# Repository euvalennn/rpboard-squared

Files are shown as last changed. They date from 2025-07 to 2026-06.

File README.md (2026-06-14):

# RPBoard²

RPBoard² is a simple RP2350-based board with multiple convenient features built-in. It's my first "actual" PCB project (I only did a hackpad before)

## Motivation

I wanted to build a devboard to learn more about actual PCB design and electronics, instead of using pre-made boards. I considered it as a personal challenge and ended up learning a lot on the two weeks it took me to make it :D

## Features:

- RP2350A MCU
- JST Debug header
- Built-in lithium battery support
- microSD card reader
- On-board RGB LED on GPIO25 (neopixel)
- QWIIC / Stemma QT I2C connector
- USB-C connector
- 16MB flash memory

## Built project:

| Front | Back |
| --- | --- |
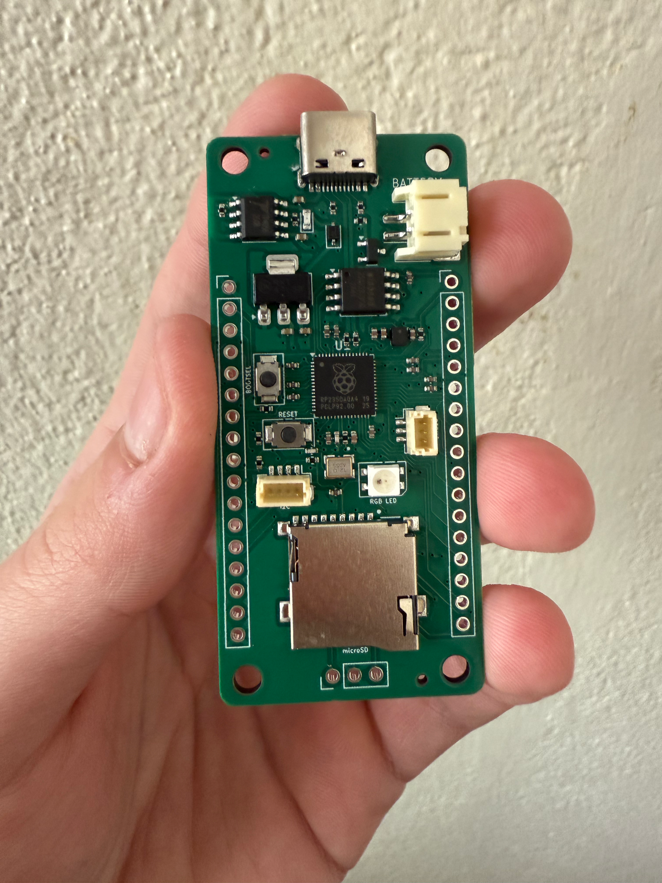
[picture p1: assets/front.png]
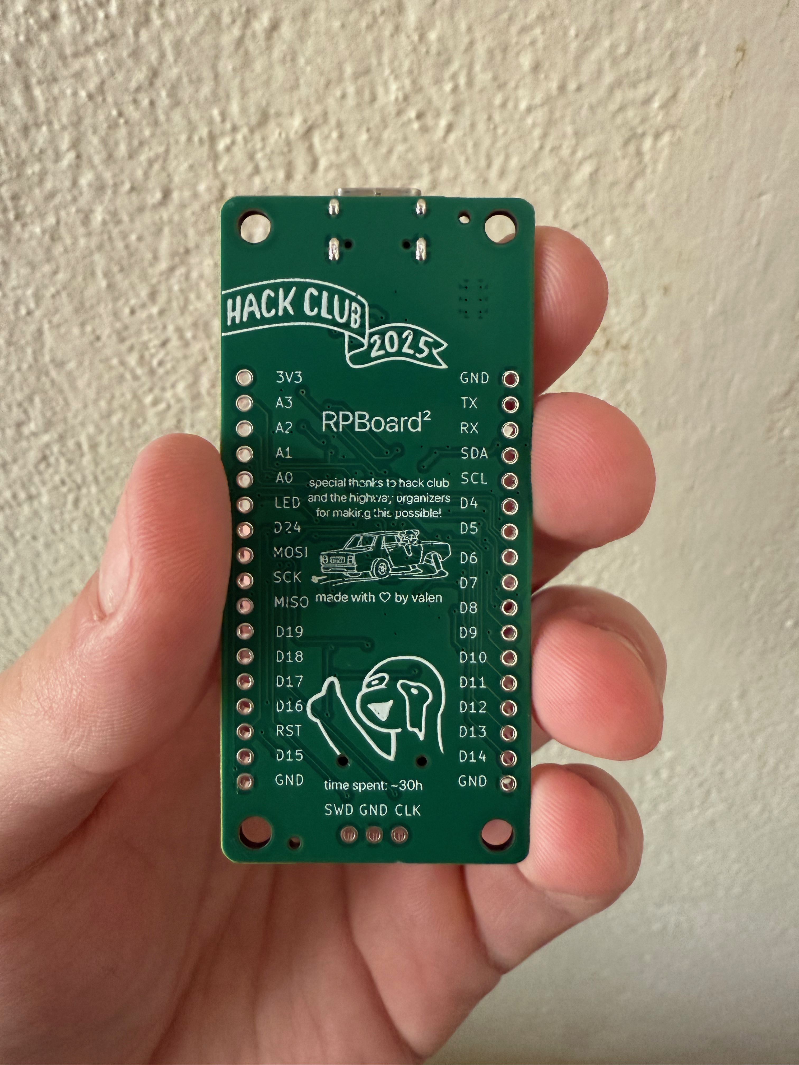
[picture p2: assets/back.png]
|  |  |

## PCB and schematic:

### Schematic:

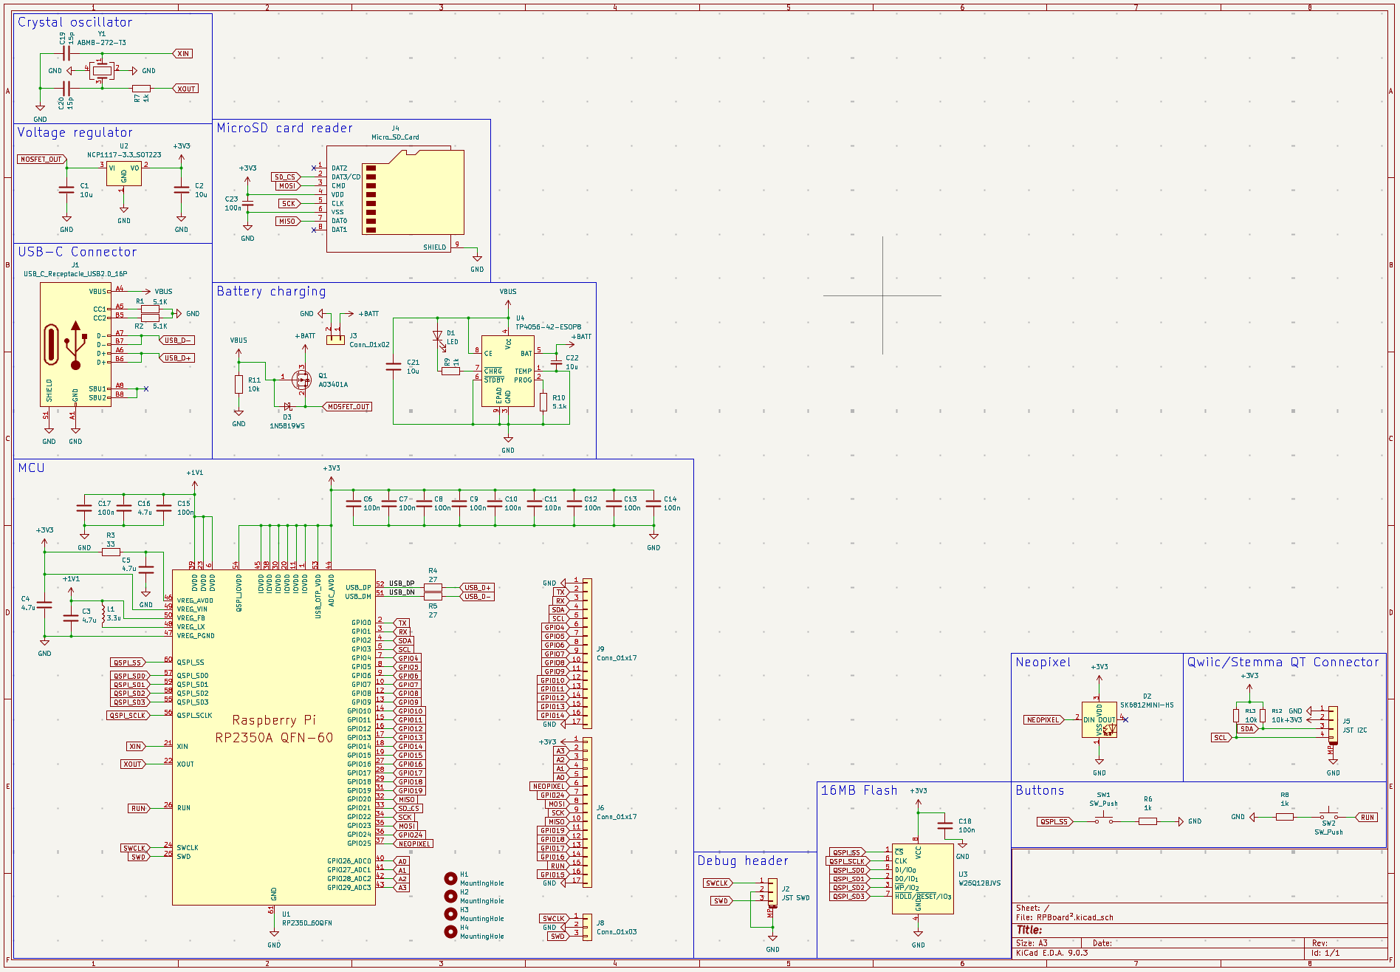
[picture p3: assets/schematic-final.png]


### PCB:

| PCB editor | 3D viewer |
| --- | --- |
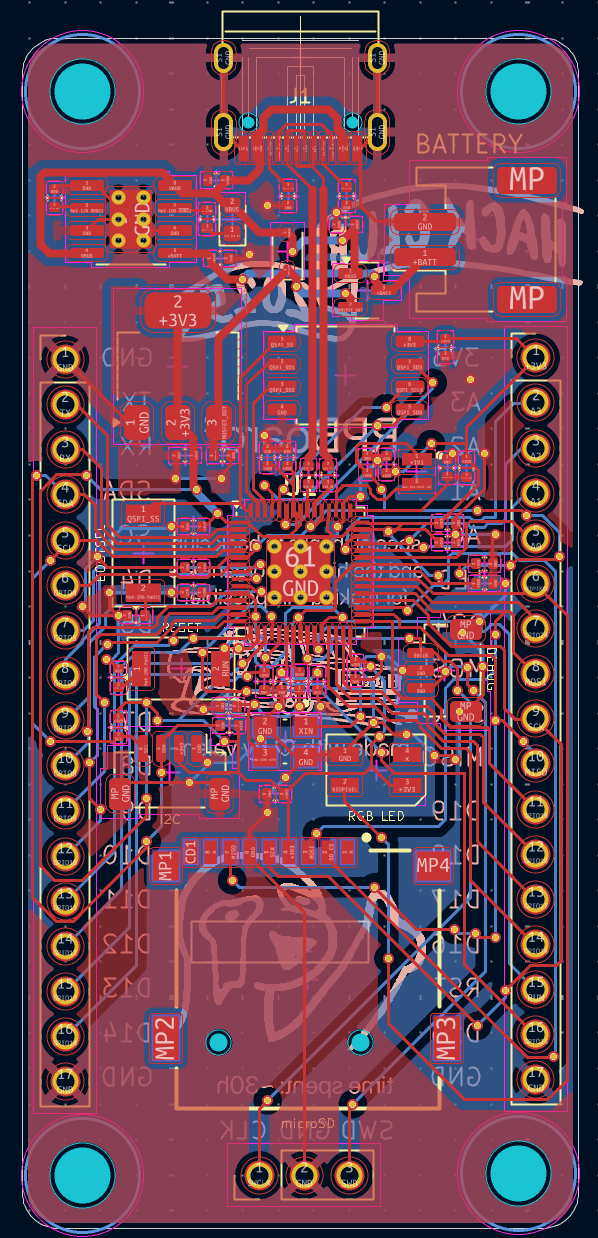
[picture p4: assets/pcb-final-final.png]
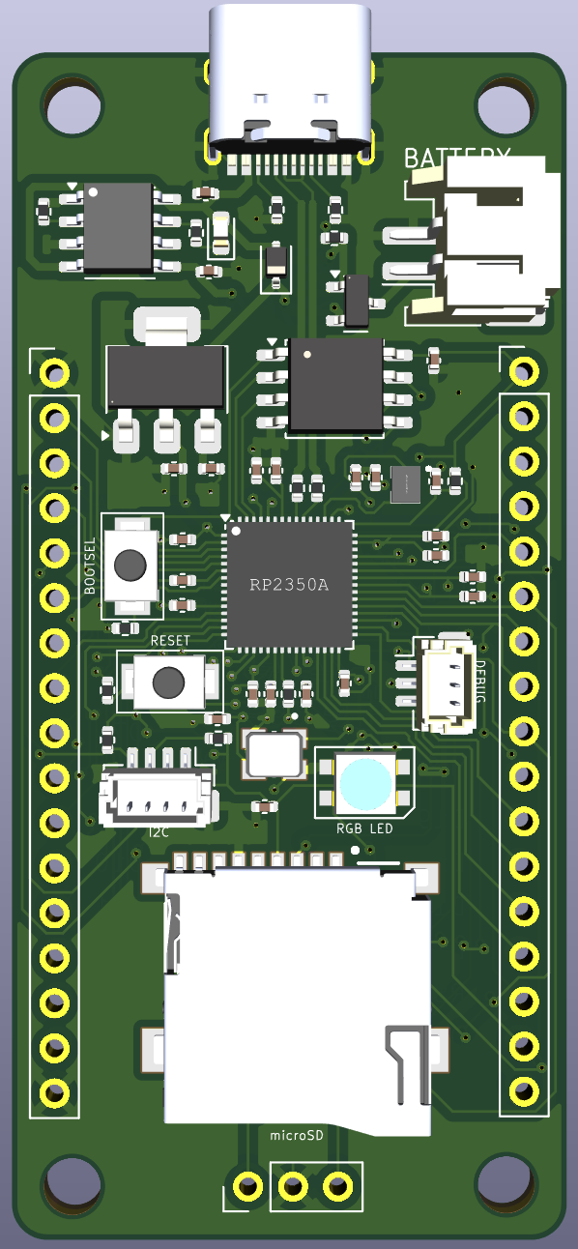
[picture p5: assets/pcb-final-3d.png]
|  |  |

Both the PCB and the schematic were designed using KiCad. The PCB is a 2-layer board with a ground pour on both layers.

## BOM:

| Name | Description | Quantity | LCSC Part # | Total price |
| --- | --- | --- | --- | --- |
| CL05A106MP5NUNC | 10V 10uF X5R ±20% 0402 Multilayer Ceramic Capacitors MLCC - SMD/SMT ROHS | 4 | C315248 | $0.1640 |
| CGA0402X7R104K160GT | 16V 100nF X7R ±10% 0402 Multilayer Ceramic Capacitors MLCC - SMD/SMT ROHS | 13 | C6119799 | $0.0342 |
| CL05A475MP5NRNC | 10V 4.7uF X5R ±20% 0402 Multilayer Ceramic Capacitors MLCC - SMD/SMT ROHS | 4 | C23733 | $0.0384 |
| CC0402JRNPO9BN150 | 50V 15pF NP0 ±5% 0402 Multilayer Ceramic Capacitors MLCC - SMD/SMT ROHS | 2 | C106997 | $0.0220 |
| XL-1608SURC-06 | 20mA 225mcd Water Clear op View Mount 620nm~630nm Red 120° 50mW 2.3V 0603 LED Indication - Discrete ROHS | 1 | C965799 | $0.0620 |
| SK6812MINI-HS | SMD,3.5x3.7mm RGB LEDs(Built-in IC) ROHS | 1 | C2922787 | $0.4665 |
| 1N5819WS | 40V 600mV@1A 1A SOD-323 Schottky Diodes ROHS | 1 | C191023 | $0.0192 |
| TYPE-C-31-M-12 | 5A 1 16P Female Type-C SMD USB Connectors ROHS | 1 | C165948 | $0.3394 |
| BM03B-SRSS-TB(LF)(SN) | 1x3P 3P SH Tin 3 -25℃~+85℃ 1A 1 1mm Copper Alloy Surface Mount,Vertical SMD,P=1mm Wire To Board Connector ROHS | 1 | C160389 | $1.1070 |
| S2B-PH-SM4-TB(LF)(SN) | 1x2P 2P PH Tin 2 -25℃~+85℃ 2A 1 2mm Copper Alloy Surface Mount, Right Angle SMD,P=2mm,Surface Mount,Right Angle Wire To Board Connector ROHS | 1 | C295747 | $0.9295 |
| TF-01A | 1.85mm Connector and Ejector MicroSD Card (TF Card) Push-Push SMD SD Card / Memory Card Connector ROHS | 1 | C91145 | $0.3372 |
| BM04B-SRSS-TB(LF)(SN) | 1x4P 4P SH Tin 4 -25℃~+85℃ 1A 1 1mm Copper Alloy Surface Mount,Vertical SMD,P=1mm Wire To Board Connector ROHS | 1 | C160390 | $0.9105 |
| AOTA-B201610S3R3-101-T | 0806 Power Inductors ROHS | 1 | C42411119 | $1.3680 |
| AO3401A | 30V 4.2A 120mΩ@2.5V 1.4W 1.3V@250uA 1 P-Channel SOT-23 MOSFETs ROHS | 1 | C347476 | $0.2990 |
| 0402WGF5101TCE | 62.5mW Thick Film Resistor 50V ±100ppm/℃ ±1% 5.1kΩ 0402 Chip Resistor - Surface Mount ROHS | 3 | C25905 | $0.0030 |
| 0402WGF1002TCE | 62.5mW Thick Film Resistor 50V ±100ppm/℃ ±1% 10kΩ 0402 Chip Resistor - Surface Mount ROHS | 3 | C25744 | $0.0030 |
| 0402WGF330JTCE | 62.5mW Thick Film Resistor 50V ±100ppm/℃ ±1% 33Ω 0402 Chip Resistor - Surface Mount ROHS | 1 | C25105 | $0.0010 |
| RC0402FR-0727RL | 62.5mW Thick Film Resistor 50V ±100ppm/℃ ±1% 27Ω 0402 Chip Resistor - Surface Mount ROHS | 2 | C138021 | $0.0120 |
| FRC0402J102 TS | 62.5mW Thick Film Resistor 50V ±100ppm/℃ ±5% 1kΩ 0402 Chip Resistor - Surface Mount ROHS | 4 | C2906899 | $0.0080 |
| TS-1088-AR02016 | Without Bracket 50mA 4mm 100,000 Cycles 12V 1.6N 3mm 2mm Round Button Surface Mount,Vertical SPST SMD Tactile Switches ROHS | 2 | C720477 | $0.1692 |
| RP2350A | QFN-60-EP(7x7) Microcontrollers (MCU/MPU/SOC) ROHS | 1 | C42411118 | $2.1330 |
| NCP1117ST33T3G | 62dB@(120Hz) 1A Fixed 3.3V Positive 20V SOT-223 Voltage Regulators - Linear, Low Drop Out (LDO) Regulators ROHS | 1 | C26537 | $0.5098 |
| W25Q128JVSIQ | 128Mbit SPI 133MHz SOIC-8-208mil NOR FLASH ROHS | 1 | C97521 | $1.9590 |
| TP4056-42-ESOP8 | 4V~8V Lithium-ion/Polymer 1 1A ESOP-8 Battery Management ROHS | 1 | C16581 | $0.3438 |
| ABM8-272-T3 | SMD3225-4P Crystals ROHS | 1 | C20625731 | $2.1000 |
| PCB Price | JLCPCB | 5 | N/A | $2.00 |
| Economic PCBA setup fee | JLCPCB | N/A | N/A | $8.00 |
| PCBA stencil | JLCPCB | N/A | N/A | $1.50 |
| Extended components fee | JLCPCB | N/A | N/A | $51.00 |
| SMT assembly | JLCPCB | N/A | N/A | $1.13 |
| Special components fee | JLCPCB | N/A | N/A | $0.06 |
| Nitrogen reflow soldering | JLCPCB | N/A | N/A | $0.82 |
| Shipping to Argentina (cheapest) | DHL Express (FedEx appears to be cheaper on cart page but adds an additional remote area surcharge at checkout, DHL ends up being the cheapest option) | N/A | N/A | $33.33 |
| Subtotal | N/A | N/A | N/A | $111.18 |
| Total after $80 JLCPCB coupon | N/A | N/A | N/A | $31.18 |

Although DHL shipping is expensive, it's the cheapest option for Argentina. FedEx has a cheaper price in the cart page, but after checking out it adds a $50+ remote area surcharge.

## Special thanks:

Thanks to Hack Club and the highway organizing team for all their efforts to make this possible. I would have never thought I'd be capable of something like this, yet highway gave me the motivation I needed to actually learn and design, and the funding to make it real.

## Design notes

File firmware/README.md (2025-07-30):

# Firmware

This basic CircuitPython code makes the integrated neopixel blink. It's a basic demo of the board's functionalities.

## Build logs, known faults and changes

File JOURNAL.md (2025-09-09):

---
title: "RPBoard²"
author: "@valen"
description: "Simple RP2350-based devboard"
created_at: "2025-07-15"
---

### Total time spent: 39h

# July 15: Started reading hardware design guide + basic schematic design

I wanted to get started doing the schematic as I was reading the guide instead of just reading, so that's what I did :D

Here's how my schematic is looking for now: (ik it's really basic but I'm just getting started and following the guide, I'll add a ton of features once I have the basics done. also I spent most of the time trying to understand what I'm doing instead of just copy pasting that's why it took me so long lol)

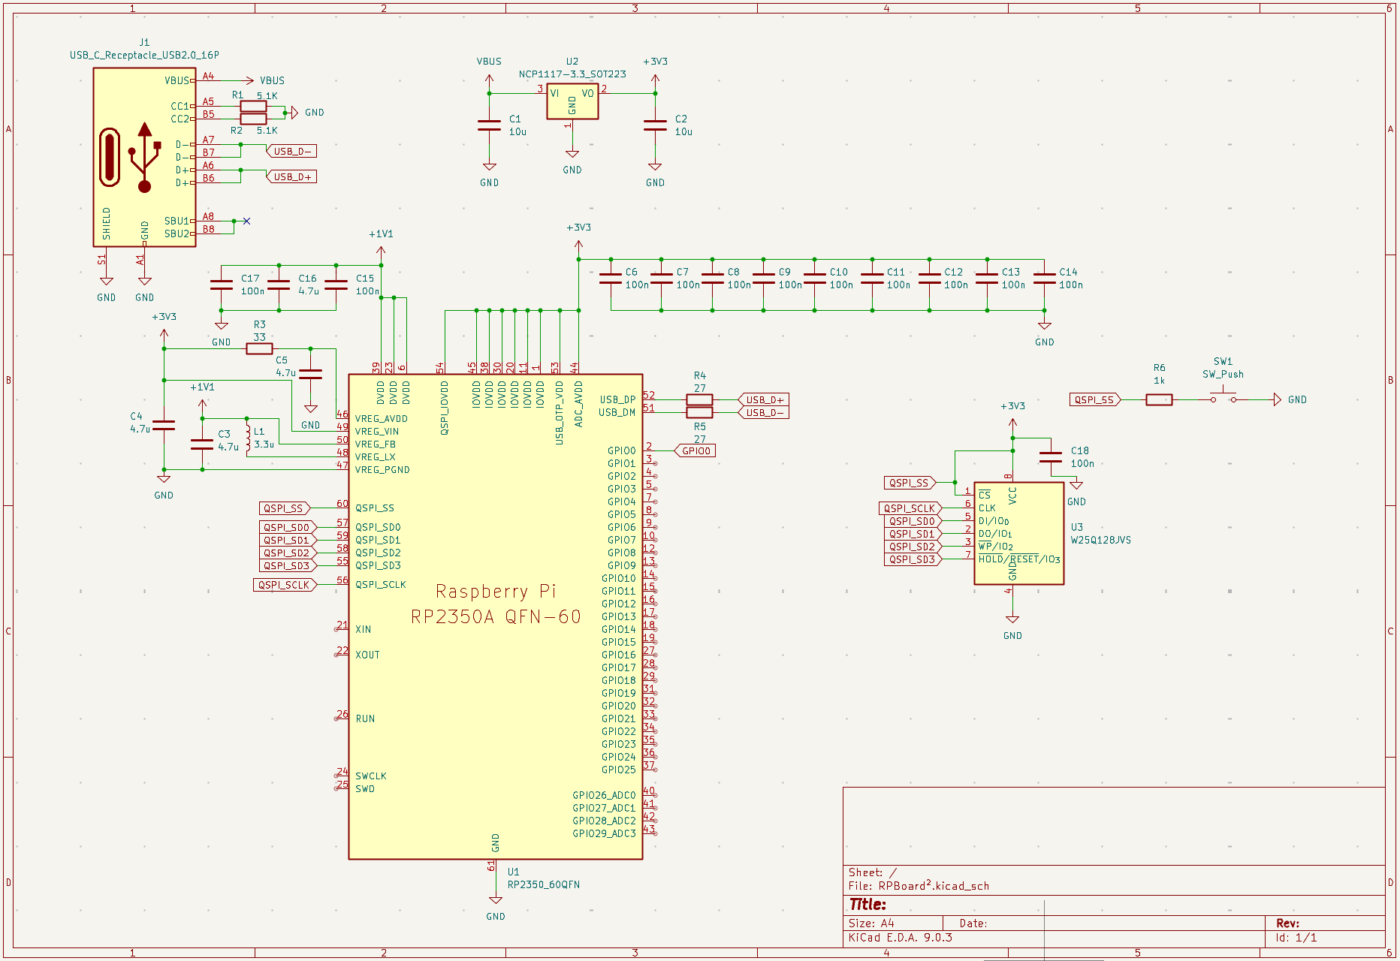
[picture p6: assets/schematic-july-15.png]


Only thing I changed for now is the USB connector for it to be USB-C, it's not really too different from the micro USB symbol but that's probably because I'm using a 16 pin connector.

As for the flash, it took me quite some time to figure out how to wire it because the guide wasn't really clear but it ended up being easier than I thought, idk why I got so confused lol

Then I also added decoupling caps on the power pins (took me some time to understand what they were and why I should add them but after quite a lot of googling I think I figured it out).

And the last thing I added to my schematic was the external components needed to make the on-chip voltage regulator work properly, I copied that from the guide since I didn't want to mess up and for some reason the guide really insists on using a specific inductor so might as well do that lmao

To finish with the basics of the schematic I'm only missing the crystal oscillator, a debug connector (optional but I'll add it anyways for convenience) and a reset button (optional too but obviously nice to have).

As for additional features, for now I'm planning on adding lipo battery support, a Qwiic connector, a microSD card slot and maybe even a small OLED depending on how much space I have left

Well hopefully tomorrow I'll finish with the basics and start adding some actually interesting features!! :D

**Time spent this session: 4h**

# July 16: Finished basic features + lot of research into charging circuit

Today I finished the basic features needed to make the board work! It's really simple though so I don't think its worth it to even include a screenshot of that.

What I did spend a lot of time on though is trying to figure out how I'd implement battery charging into the board, and after a few hours of googling and reading datasheets I think I'm gonna use a TP4056 with its "typical application" circuit as the charging IC (screenshot below) and then use a MOSFET so load switches to VBUS when USB is plugged in. From what I've seen I also have to include a diode in the load sharing circuit for protection. I'll try to add the charging aspect tomorrow and then see if someone can take a look at my schematic and tell me if there's any mistakes, maybe I'm overthinking this too much lol

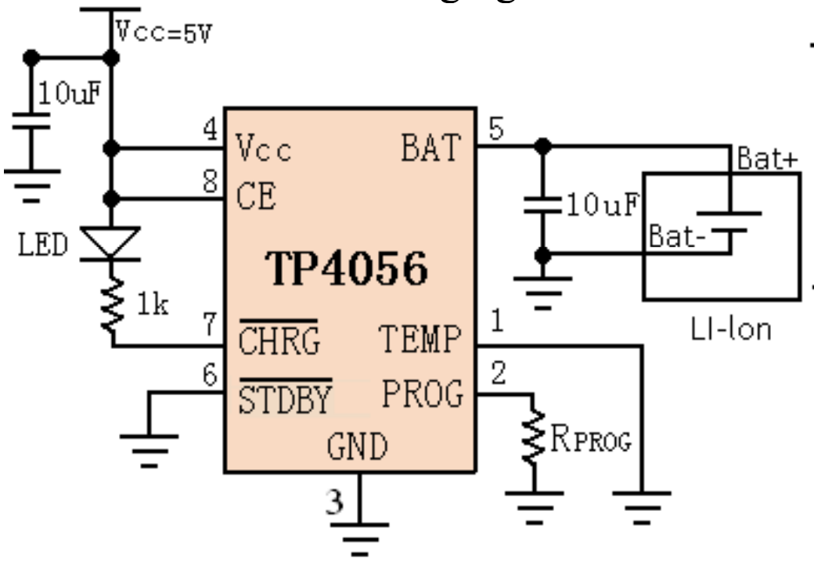
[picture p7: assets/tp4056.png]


microSD card reader shouldn't be too hard to wire, and a Qwiic connector should be even easier. I'm not sure if I'll end up adding the OLED though, since I'm planning on getting PCBA for this board and also aliexpress takes like 2 months to ship to me so I wouldn't be able to build it in time unless I source it locally (in that case I'd pay the price difference between getting it locally and ali out of pocket since the cost of locally sourcing an OLED is lower than the customs fees I'd be charged with aliexpress lmao)

Hopefully this approach works because I spent a lot of time figuring it out 😭

**Time spent this session: 3h**

# July 17: Finished charging circuit + tidied up schematic

I finally finished implementing the charging circuit in my schematic, it took me way longer than it should have but I wanted to make sure I was doing everything right becasue no power = no board :(

This is how my charging circuit looks now:

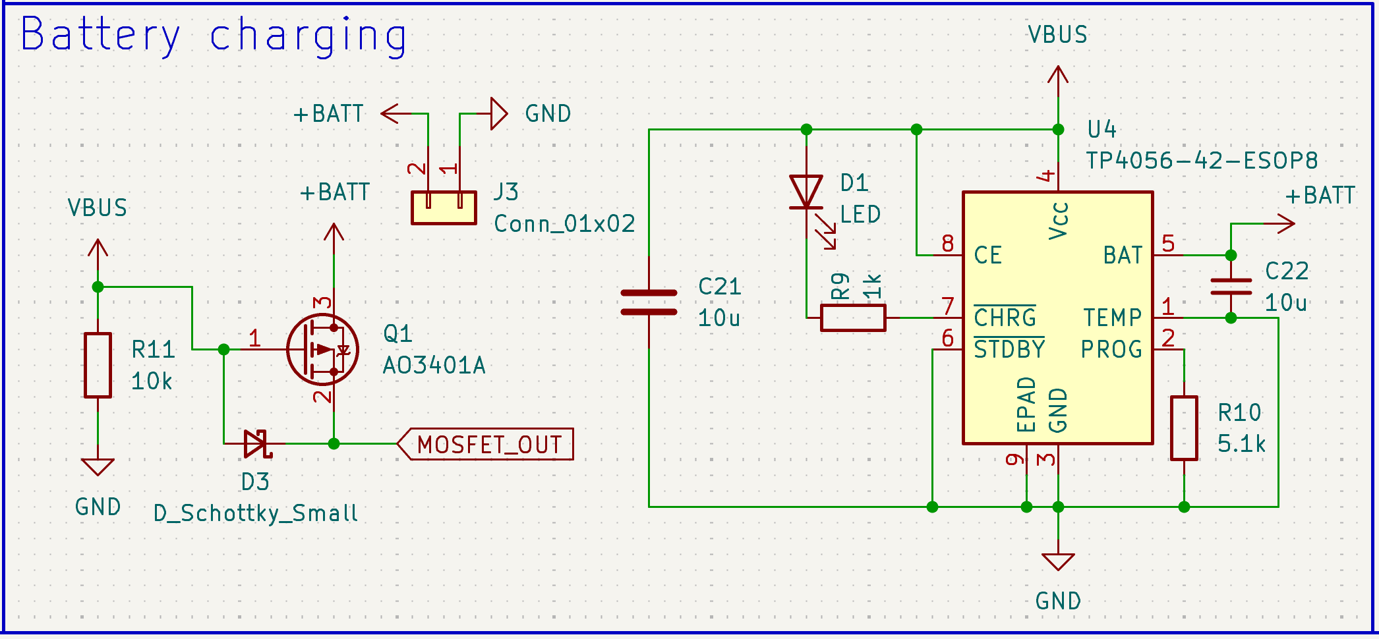
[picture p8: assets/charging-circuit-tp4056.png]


The 5.1k resistor should give me a charging current of around 200-250 mA, which I think is fine for small LiPo batteries. Anyways, if I were to change my mind later I could just swap that resistor.

I also switched the voltage regulator to take in the output from the MOSFET instead of just VBUS:

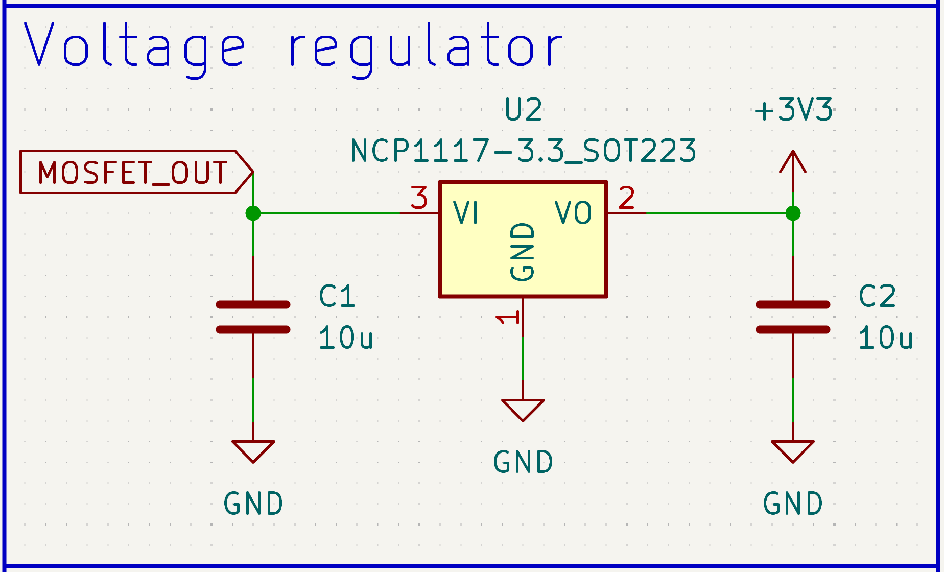
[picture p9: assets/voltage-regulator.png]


Finally, I tidied up the schematic, changed the size to A3 and divided everything into sections so it's easier to read and work with:

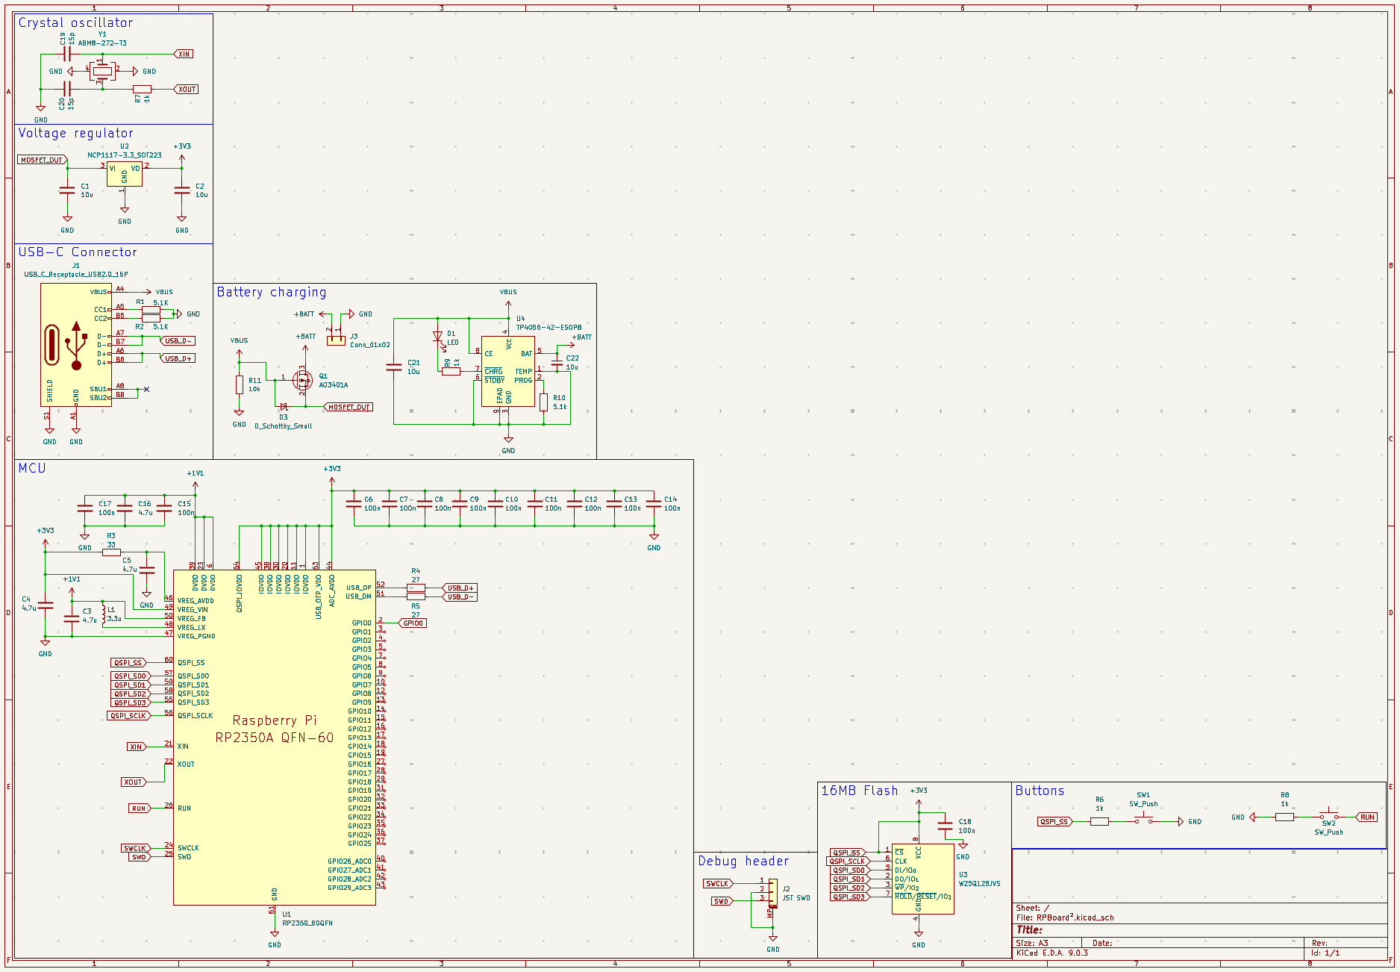
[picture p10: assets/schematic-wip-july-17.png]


I think tomorrow I'll be able to fully finish my schematic and maybe start with the PCB, though I'd like to get someone to take a look at it and tell me if there are any obvious mistakes before starting with the PCB

**Time spent this session: 2h**

# July 18: Finished schematic + started assigning footprints

I finished the schematic today, added the microSD card reader (didn't know how to wire it at all, but I found a nice video that explained how SPI worked and I also found the RP2350 datasheet to find out what pins I had to use), a neopixel on pin 25 (if it makes assembly too hard / costly I might remove it) and a 4 pin Qwiic / Stemma QT connector.

This is how the schematic is looking as of now:

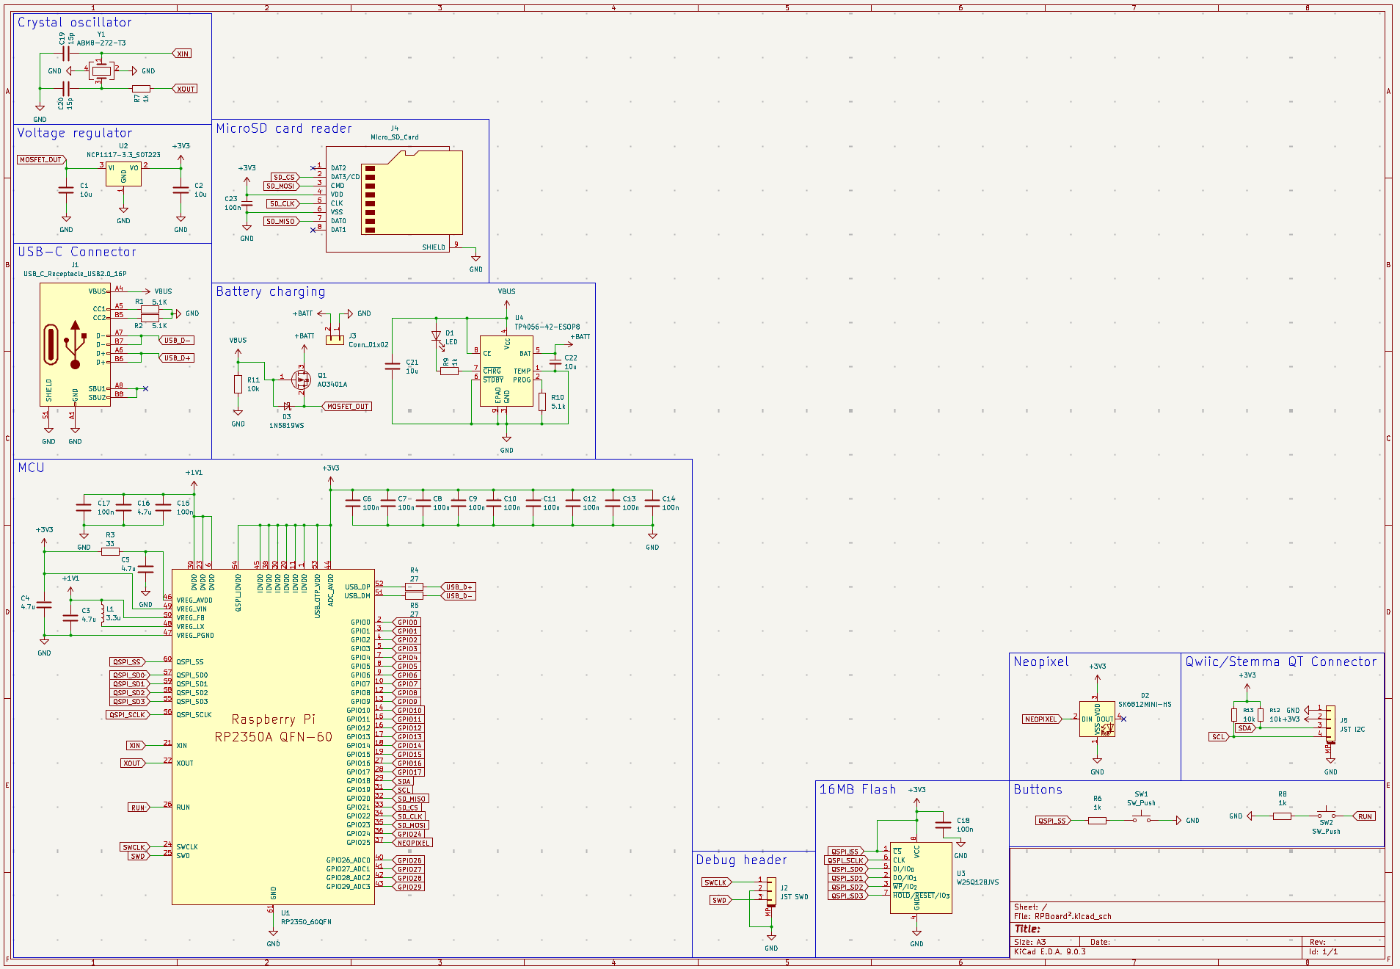
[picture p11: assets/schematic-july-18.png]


I also started looking for footprints and assigning them so I can already get started on the PCB. Though I'll probably wait for someone to take a look at it before starting, someone suggested I send it in the KiCad discord server so I'll probably do that (after creating a new account I haven't used discord in ages lol)

Hopefully I'm able to finish this board soon, though with the time it took me to make the schematic I don't expect the PCB to be any easier 😭

**Time spent this session: 2h**

# July 22: Got my schematic reviewed + started PCB

Today I finally sent my schematic to the KiCad discord server and someone helped me with it. First, they told me to specify the caps for the LDO because there are limits on ESR (will do), secondly, they told me to wire the TEMP pin of the TP4056 and not just ground it, but I can't really do that since afaik I'd need to use 3-wire LiPos with a thermistor so I'll just keep that pin grounded I guess lol

Then last thing they suggested is that I review the MOSFET circuit, but after chatting back and forth for a while I'm pretty sure it'll work, it's similar to a diode but without the voltage drop.

After all this, I assigned all footprints (had to make one myself for the push buttons but it's just two pads) and imported everything to the PCB editor. Then I started positioning and laying out the components on the board, it's still not done yet but this is how it's looking for now (focused on the decoupling capacitors, definitely not even close to finished yet):

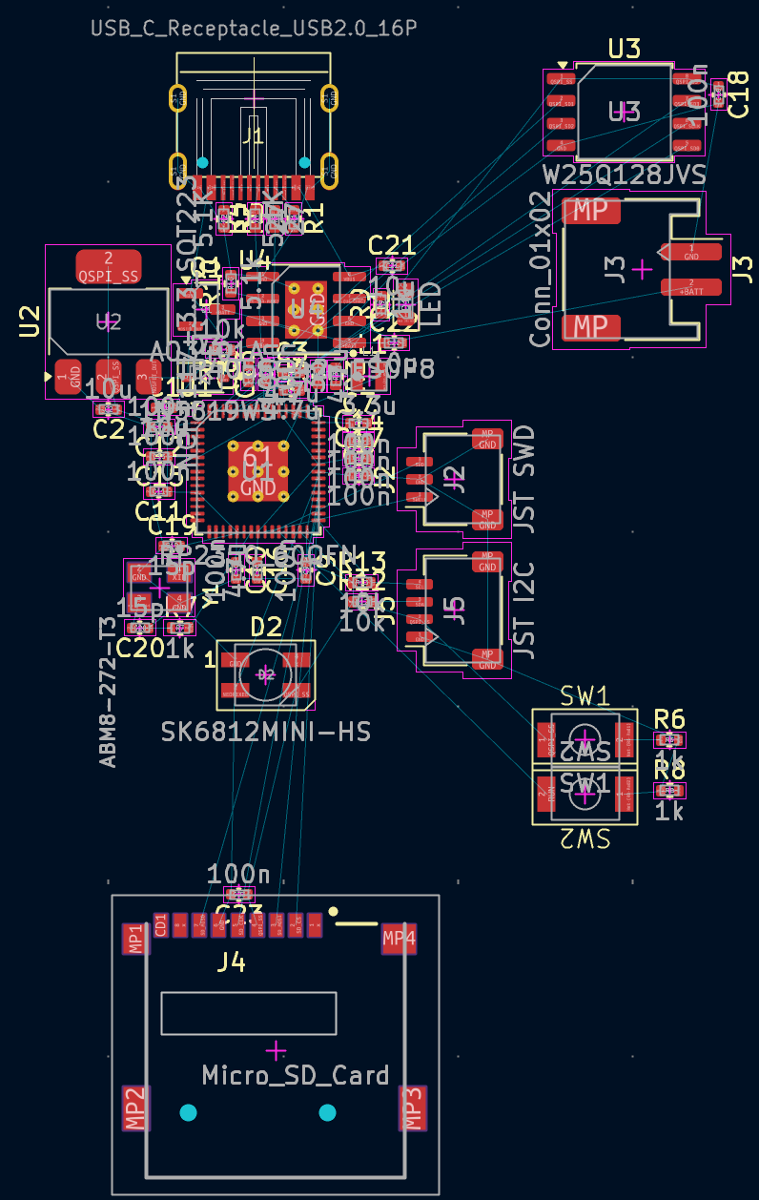
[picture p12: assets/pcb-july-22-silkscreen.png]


And here's how it looks like with the silkscreen layer disabled:

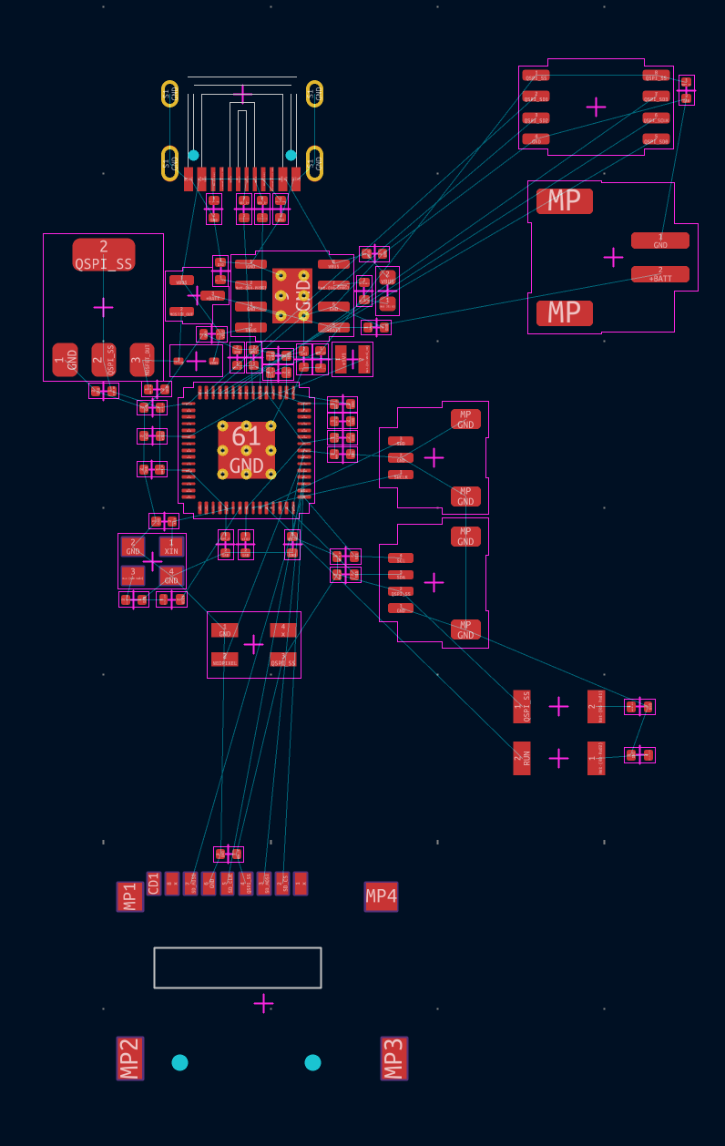
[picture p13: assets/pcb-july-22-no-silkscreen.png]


I'll keep working on it, I don't think it should be too hard now but we'll see :pf:

**Time spent this session: 5h**

# July 24: Improved PCB layout, hopefully ready to route

Today I continued working on the PCB, and I think I finally have it sort of ready to route (might change the layout later if routing is too hard though). I assigned 3D models to every footprint, put everything together and also added through-holes for headers and mounting holes. Here's how the PCB is looking for now:

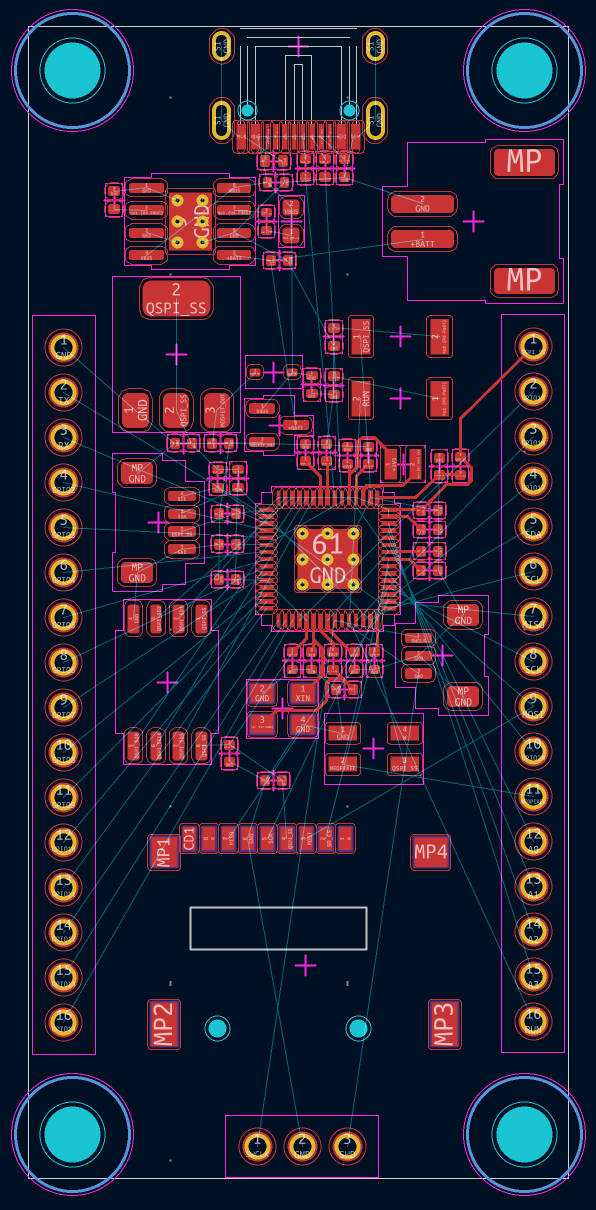
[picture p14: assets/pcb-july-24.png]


And here it is in the 3D viewer:

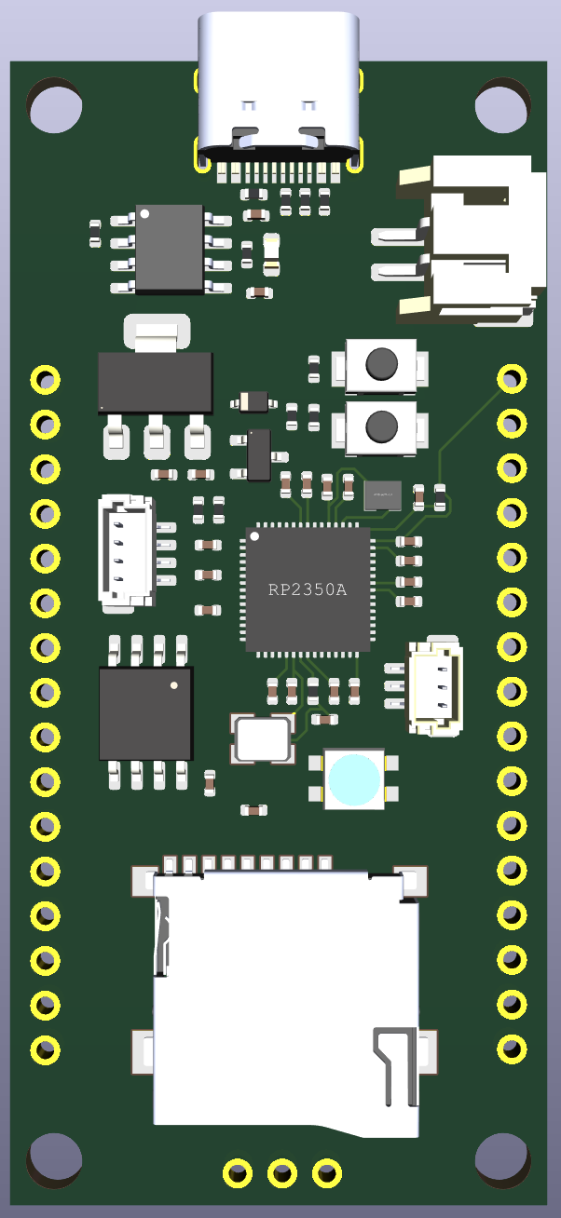
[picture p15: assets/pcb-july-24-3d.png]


I'll fillet the corners and add a shit ton of silkscreen after finishing routing everything. Maybe I'll have to change the layout again when I realize everything's impossible to route though so we'll see :pf: (also I know for sure I'll change the headers layout because right now it's not ordered to match the MCU pins)

I also changed the footprint for the Stemma QT and debug connectors to be vertical so I can save space on that.

Now I guess I can just get started routing and hopefully finish the PCB soon!! I really want to finish it I've dedicated most of my free time to working on this :heavysob:

**Time spent this session: 4h**

# July 25: Started routing and changed layout (again)

I finally got onto routing the PCB today! I spent a lot of time moving stuff around and trying different positions, and I also changed the header pins connections to match the order of the physical MCU pins. I also realized the flash memory chip was not wired properly in my schematic, the CS pin was also wired to 3V3 (originally it was for an optional pull-up resistor, but I didn't realize if I didn't include the pull-up I also wouldn't need to wire it to 3V3 :pf:) but that was a quick fix, just removed the connection and updated the PCB.

After a few hours of routing, I sent my progress to the Slack and realized the MCU wasn't centered which I haven't really thought of before, so I moved some stuff to make space for the MCU and had to delete almost all the tracks I've routed :heavysob:

This is how the PCB is looking for now:

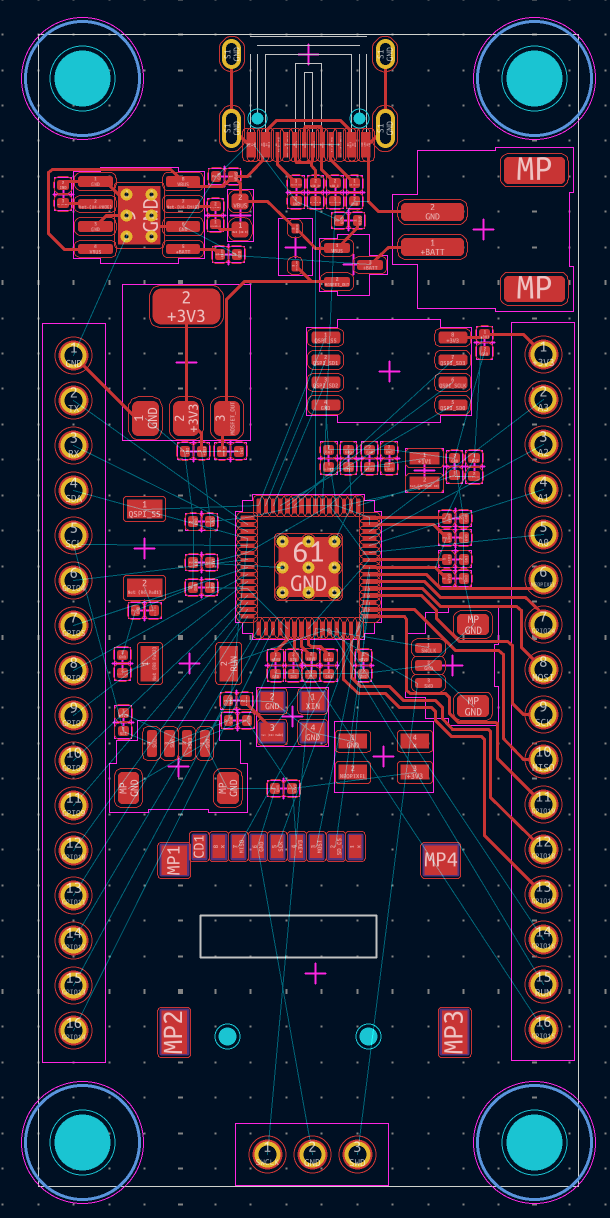
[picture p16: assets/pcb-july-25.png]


I'll add a ground pour on both layers when I finish routing, along with a fillet for the corners and silkscreen!! (what I'm looking forward to the most lol)

**Time spent this session: 4h**

# July 27: More routing (almost finished)!

Today I continued routing the PCB traces and added a ground pour on the front and back layers, I don't think I have much more to say about that lol

I also added a net label to the USB_DP and USB_DM pins of the MCU so KiCad lets me route a differential pair for the USB data lines, here's a screenshot of that in the schematic:

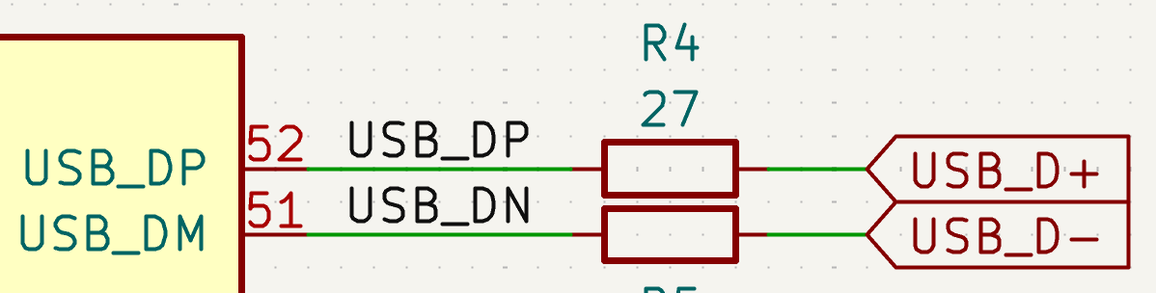
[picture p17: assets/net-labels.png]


And here's a screenshot of how the PCB is looking for now:

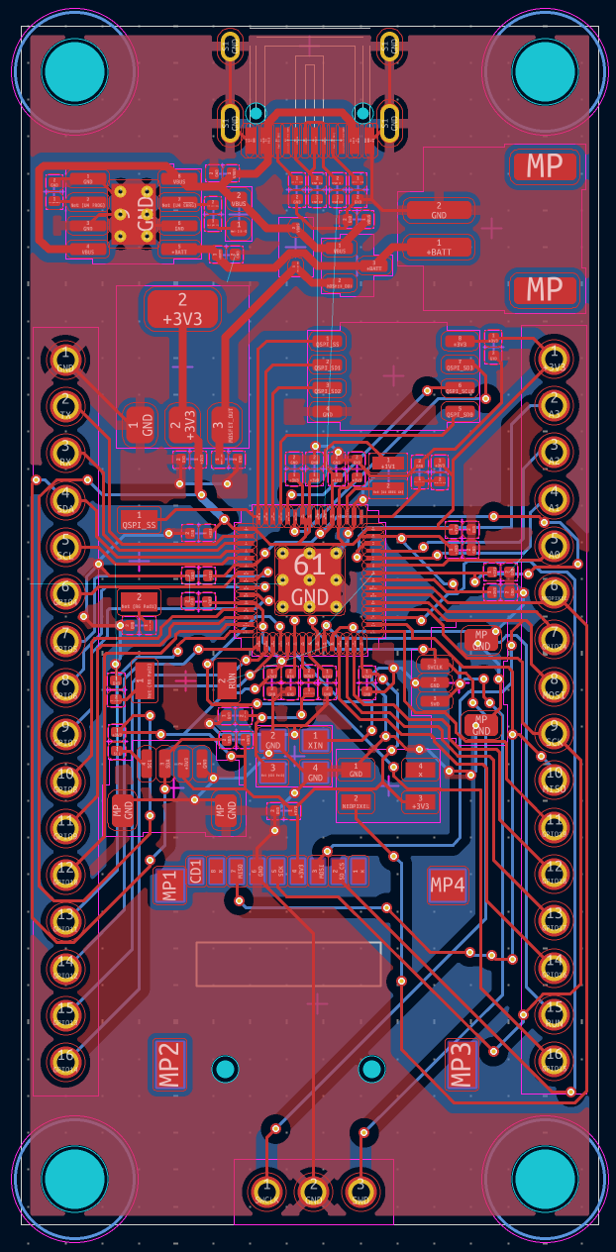
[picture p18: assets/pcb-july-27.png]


I'm only missing 10 more routes and after that I should be finished with the PCB!! yayyy

Hopefully there aren't any big mistakes I didn't notice because if there are I am NOT gonna be able to submit before the deadline 😭

**Time spent this session: 5h**

# July 29: Finished the PCB!!

I finally finished the PCB! :yay:

I routed the missing traces (had to change some existing routes positions and add some vias but didn't change too much), added one more GND pin to each header, added silkscreen and also filleted the PCB corners. I'll attach a photo of the PCB in the editor, the 3D viewer and also a screenshot of the schematic.

PCB:

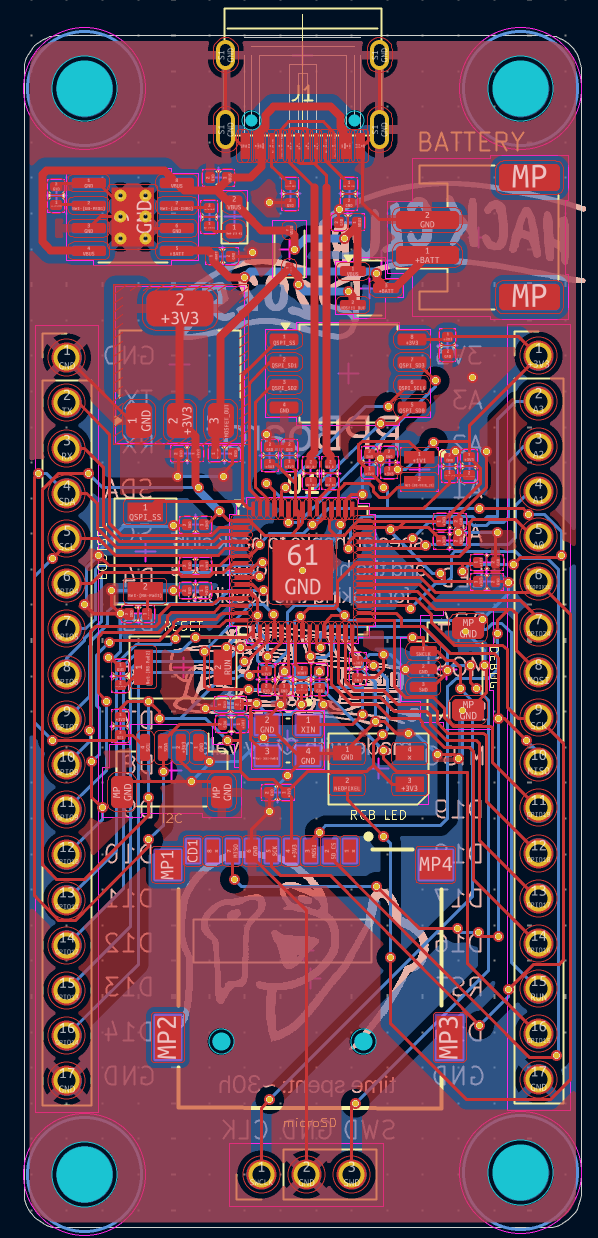
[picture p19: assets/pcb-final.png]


3D viewer:



Schematic:



I guess I'm ready to submit now!! :D

All I need to submit now is the README, the BOM and well basically everything but the PCB lol

**Time spent this session: 4h**

# August 22: PCBs arrived!!!

Today I finally got my PCBs! There's not much to say about the building process since they came already assembled. Only "issue" I had with it was that when I flashed CircuitPython + my example code it didn't work, but then I realized it was becasue I hadn't copied over the libraries to the board so after doing that it did work haha

Also, I got started with the magazine page, I have it pretty much ready except for some changes I'll make tomorrow.

Here are some pictures of the front and back of the board:

| Front | Back |
| --- | --- |
|  |  |

**Time spent this session: 3h**

# August 23: Finished magazine + Reddit post

I finished my magazine page today. I'm pretty happy with the result, especially considering I've never used Figma before (it's actually pretty nice and easy to use I see why acon likes it so much now lol)

I also posted my project to r/electronics, r/raspberry_pi and r/embedded, though r/electronics instantly deleted my post, probably because I've never used Reddit before so I had to post from a new account.

Now I only have to do the demo video, I'm kind of scared because my pronunciation and overall speaking skills in english are awful but I'll try my best haha

**Time spent this session: 2h**

# August 24: Finally recorded the demo vid!

Today I finally stopped procrastinating on recording the video and did it, it's a little short since there's not much to show about a devboard but still I think it's a nice demo, also listening to it maybe I'm not THAT bad at english lol

Well I think that's it! I already edited the demo video so all that's left to do now is add the build images to my readme and submit the form :D

**Time spent this session: 1h**

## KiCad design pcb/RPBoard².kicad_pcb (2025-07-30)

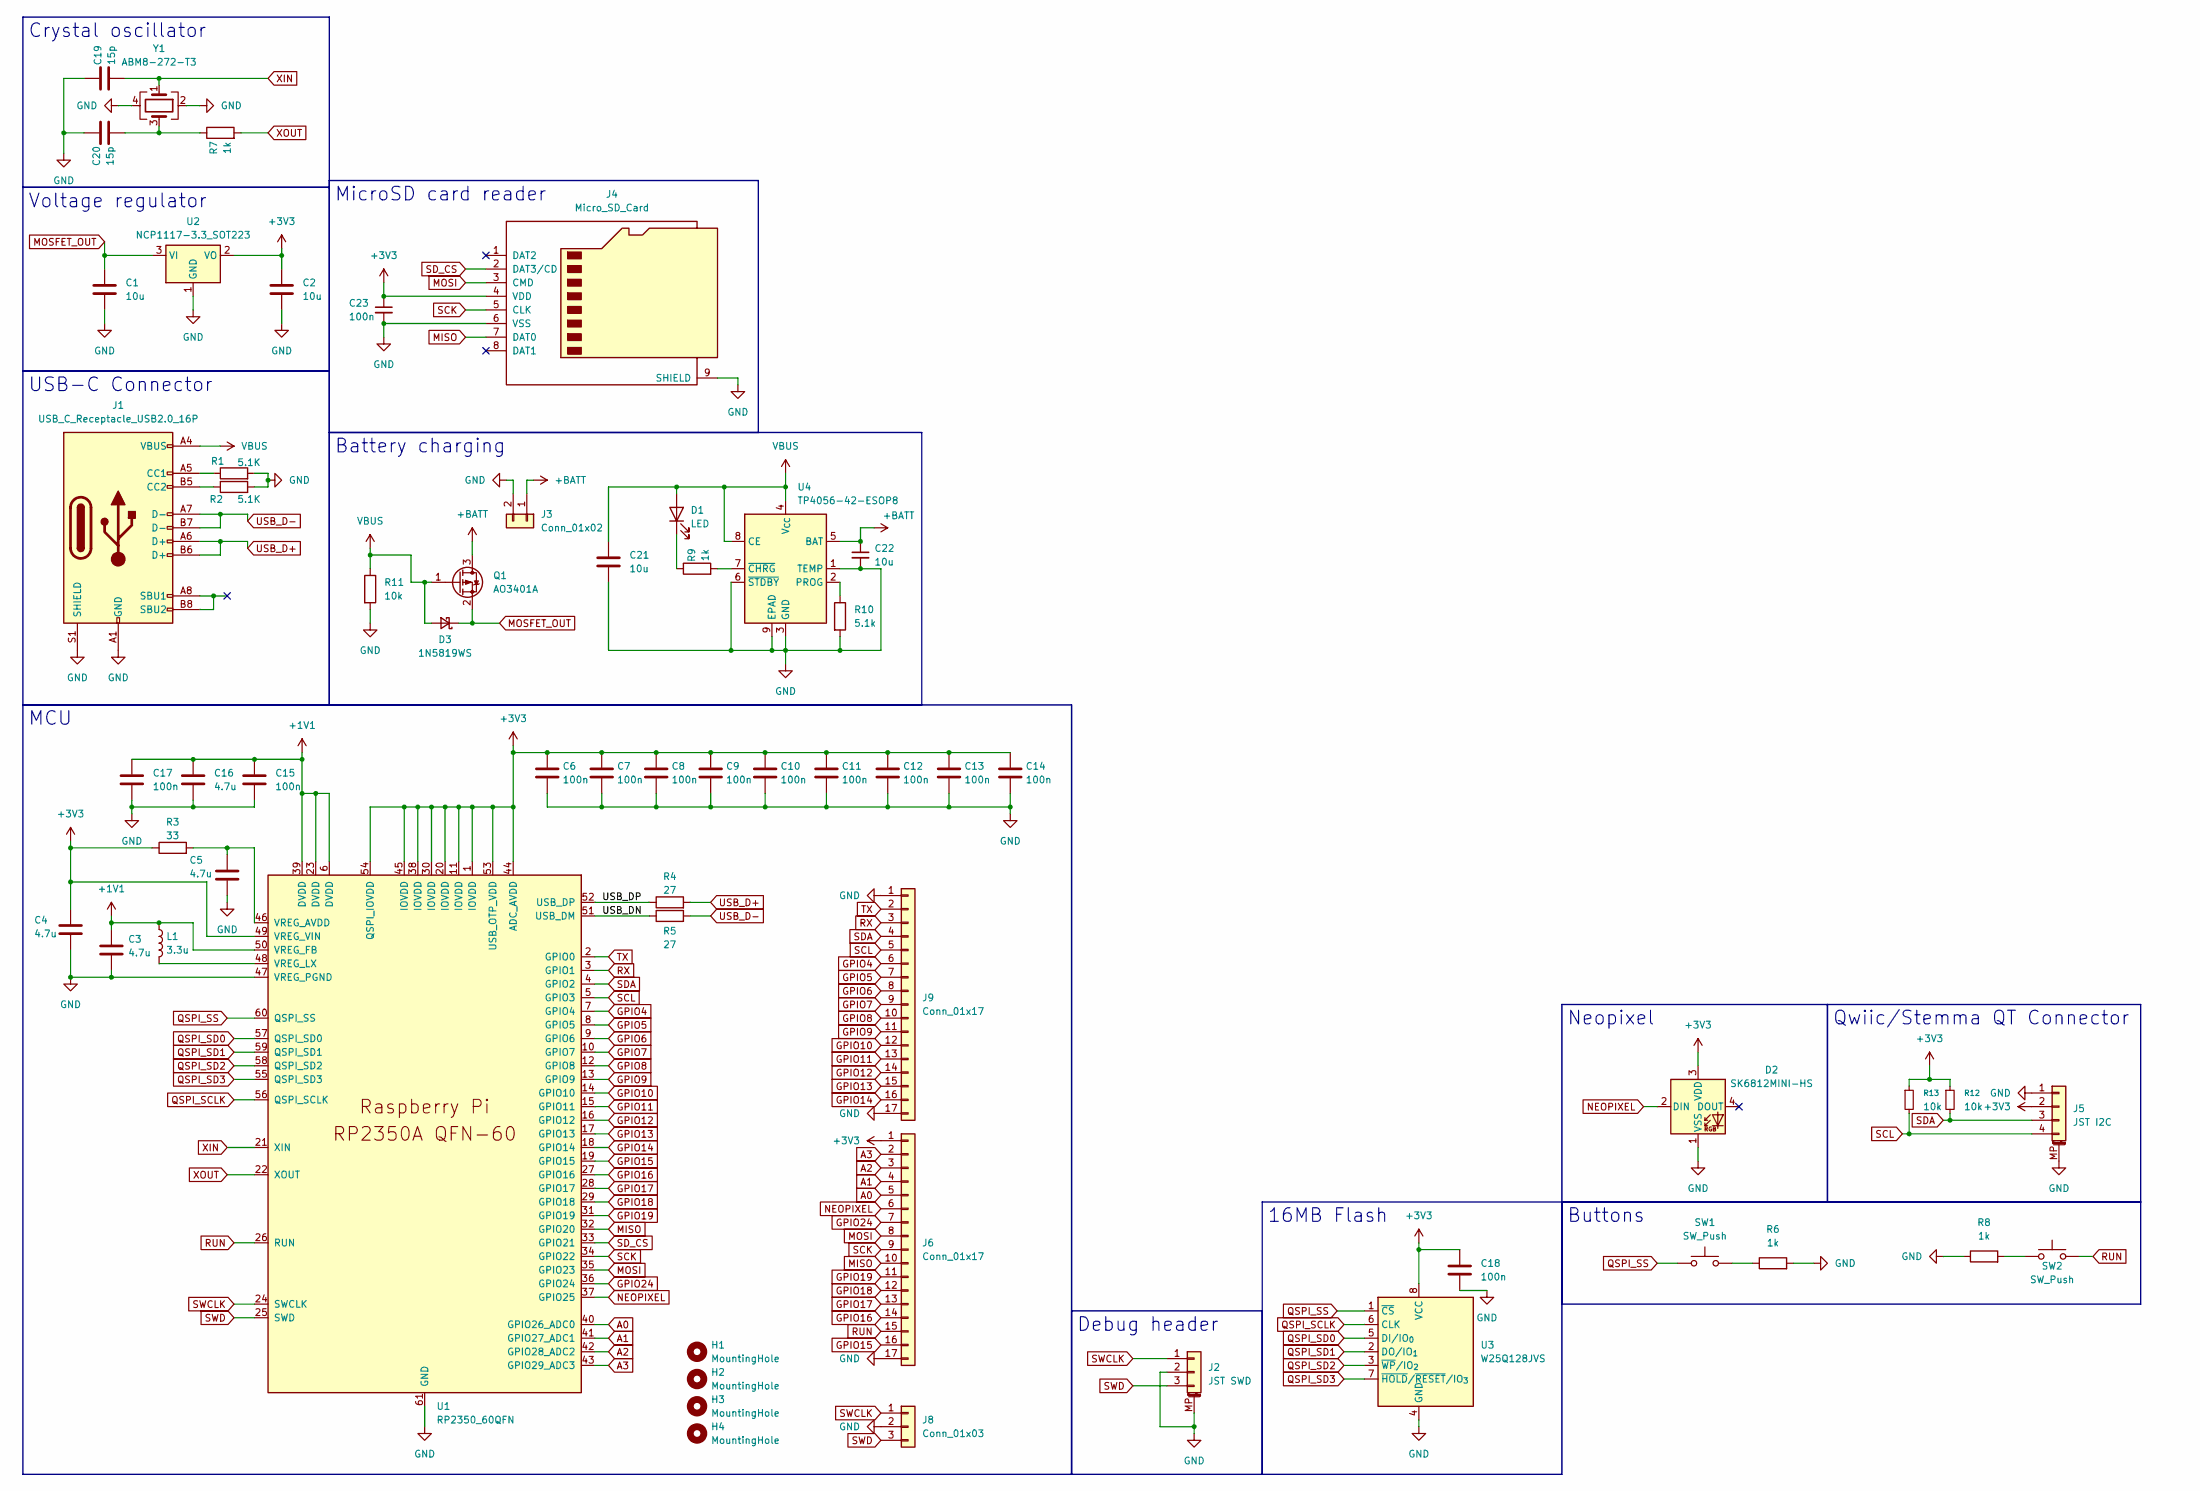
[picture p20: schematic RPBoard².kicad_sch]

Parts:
C1, C2, C21, C22: 10u; C_0402_1005Metric
C3, C4, C5, C16: 4.7u; C_0402_1005Metric
C6, C7, C8, C9, C10, C11, C12, C13, C14, C15, C17, C18, C23: 100n; C_0402_1005Metric
C19, C20: 15p; C_0402_1005Metric
D1: LED; LED_0603_1608Metric
D2: SK6812MINI-HS; LED_SK6812MINI_PLCC4_3.5x3.5mm_P1.75mm
D3: 1N5819WS; D_SOD-323
H1, H2, H3, H4: MountingHole; MountingHole_3.2mm_M3
J1: USB_C_Receptacle_USB2.0_16P; TYPE-C-31-M-12
J2: JST SWD; JST_SH_BM03B-SRSS-TB_1x03-1MP_P1.00mm_Vertical
J3: Conn_01x02; JST_PH_S2B-PH-SM4-TB_1x02-1MP_P2.00mm_Horizontal
J4: Micro_SD_Card; TF-01A
J5: JST I2C; JST_SH_BM04B-SRSS-TB_1x04-1MP_P1.00mm_Vertical
J6, J9: Conn_01x17; PinHeader_1x17_P2.54mm_Vertical
J8: Conn_01x03; PinHeader_1x03_P2.54mm_Vertical
L1: 3.3u; L_pol_2016
Q1: AO3401A; SOT-23
R1, R2: 5.1K; R_0402_1005Metric
R3: 33; R_0402_1005Metric
R4, R5: 27; R_0402_1005Metric
R6, R7, R8, R9: 1k; R_0402_1005Metric
R10: 5.1k; R_0402_1005Metric
R11, R12, R13: 10k; R_0402_1005Metric
SW1, SW2: SW_Push; TS-1088-ARXXX
U1: RP2350_60QFN; QFN-60-1EP_7x7mm_P0.4mm_EP3.4x3.4mm
U2: NCP1117-3.3_SOT223; SOT-223-3_TabPin2
U3: W25Q128JVS; SOIC-8_5.3x5.3mm_P1.27mm
U4: TP4056-42-ESOP8; SOIC-8-1EP_3.9x4.9mm_P1.27mm_EP2.41x3.3mm_ThermalVias
Y1: ABM8-272-T3; XTAL_ABM8-272-T3

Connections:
+1V1: C3.1, C15.1, C16.1, C17.1, L1.1, U1.6 (DVDD), U1.23 (DVDD), U1.39 (DVDD), U1.50 (VREG_FB)
+3V3: C2.1, C4.1, C6.1, C7.1, C8.1, C9.1, C10.1, C11.1, C12.1, C13.1, C14.1, C18.1, C23.1, D2.3 (VDD), J4.4 (VDD), J5.2, J6.1, R3.1, R12.1, R13.1, U1.1 (IOVDD), U1.11 (IOVDD), U1.20 (IOVDD), U1.30 (IOVDD), U1.38 (IOVDD), U1.44 (ADC_AVDD), U1.45 (IOVDD), U1.49 (VREG_VIN), U1.53 (USB_OTP_VDD), U1.54 (QSPI_IOVDD), U2.2 (VO), U3.8 (VCC)
+BATT: C22.1, J3.1, Q1.3 (D), U4.5 (BAT)
/USB_DN: R5.1, U1.51 (USB_DM)
/USB_DP: R4.1, U1.52 (USB_DP)
A0: J6.5, U1.40 (GPIO26_ADC0)
A1: J6.4, U1.41 (GPIO27_ADC1)
A2: J6.3, U1.42 (GPIO28_ADC2)
A3: J6.2, U1.43 (GPIO29_ADC3)
GND: C1.2, C2.2, C3.2, C4.2, C5.2, C6.2, C7.2, C8.2, C9.2, C10.2, C11.2, C12.2, C13.2, C14.2, C15.2, C16.2, C17.2, C18.2, C19.1, C20.1, C21.2, C22.2, C23.2, D2.1 (VSS), J1.A1 (GND), J1.A12 (GND), J1.B1 (GND), J1.B12 (GND), J1.S1 (SHIELD), J2.2, J2.MP (MountPin), J3.2, J4.6 (VSS), J4.9 (SHIELD), J5.1, J5.MP (MountPin), J6.17, J8.2, J9.1, J9.17, R1.2, R2.2, R6.2, R8.1, R10.2, R11.2, U1.47 (VREG_PGND), U1.61 (GND), U2.1 (GND), U3.4 (GND), U4.1 (TEMP), U4.3 (GND), U4.6 (~STDBY), U4.9 (EPAD), Y1.2, Y1.4
GPIO4: J9.6, U1.7 (GPIO4)
GPIO5: J9.7, U1.8 (GPIO5)
GPIO6: J9.8, U1.9 (GPIO6)
GPIO7: J9.9, U1.10 (GPIO7)
GPIO8: J9.10, U1.12 (GPIO8)
GPIO9: J9.11, U1.13 (GPIO9)
GPIO10: J9.12, U1.14 (GPIO10)
GPIO11: J9.13, U1.15 (GPIO11)
GPIO12: J9.14, U1.16 (GPIO12)
GPIO13: J9.15, U1.17 (GPIO13)
GPIO14: J9.16, U1.18 (GPIO14)
GPIO15: J6.16, U1.19 (GPIO15)
GPIO16: J6.14, U1.27 (GPIO16)
GPIO17: J6.13, U1.28 (GPIO17)
GPIO18: J6.12, U1.29 (GPIO18)
GPIO19: J6.11, U1.31 (GPIO19)
GPIO24: J6.7, U1.36 (GPIO24)
MISO: J4.7 (DAT0), J6.10, U1.32 (GPIO20)
MOSFET_OUT: C1.1, D3.1 (K), Q1.2 (S), U2.3 (VI)
MOSI: J4.3 (CMD), J6.8, U1.35 (GPIO23)
NEOPIXEL: D2.2 (DIN), J6.6, U1.37 (GPIO25)
unnamed: C20.2, R7.1, Y1.3
unnamed: D1.1 (K), R9.1
unnamed: J1.A5 (CC1), R1.1
unnamed: J1.B5 (CC2), R2.1
unnamed: R6.1, SW1.2
unnamed: R8.2, SW2.1
unnamed: C5.1, R3.2, U1.46 (VREG_AVDD)
unnamed: L1.2, U1.48 (VREG_LX)
unnamed: R10.1, U4.2 (PROG)
unnamed: R9.2, U4.7 (~CHRG)
QSPI_SCLK: U1.56 (QSPI_SCLK), U3.6 (CLK)
QSPI_SD0: U1.57 (QSPI_SD0), U3.5 (DI/IO_{0})
QSPI_SD1: U1.59 (QSPI_SD1), U3.2 (DO/IO_{1})
QSPI_SD2: U1.58 (QSPI_SD2), U3.3 (~WP/IO_{2})
QSPI_SD3: U1.55 (QSPI_SD3), U3.7 (~HOLD/~RESET/IO_{3})
QSPI_SS: SW1.1, U1.60 (QSPI_SS), U3.1 (~CS)
RUN: J6.15, SW2.2, U1.26 (RUN)
RX: J9.3, U1.3 (GPIO1)
SCK: J4.5 (CLK), J6.9, U1.34 (GPIO22)
SCL: J5.4, J9.5, R13.2, U1.5 (GPIO3)
SDA: J5.3, J9.4, R12.2, U1.4 (GPIO2)
SD_CS: J4.2 (DAT3/CD), U1.33 (GPIO21)
SWCLK: J2.1, J8.1, U1.24 (SWCLK)
SWD: J2.3, J8.3, U1.25 (SWD)
TX: J9.2, U1.2 (GPIO0)
USB_D+: J1.A6 (D+), J1.B6 (D+), R4.2
USB_D-: J1.A7 (D-), J1.B7 (D-), R5.2
VBUS: C21.1, D1.2 (A), D3.2 (A), J1.A4 (VBUS), J1.A9 (VBUS), J1.B4 (VBUS), J1.B9 (VBUS), Q1.1 (G), R11.1, U4.4 (V_{CC}), U4.8 (CE)
XIN: C19.2, U1.21 (XIN), Y1.1
XOUT: R7.2, U1.22 (XOUT)

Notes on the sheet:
MCU
16MB Flash
Crystal oscillator
Buttons
Voltage regulator
Qwiic/Stemma QT Connector
MicroSD card reader
USB-C Connector
Battery charging
Neopixel
Debug header

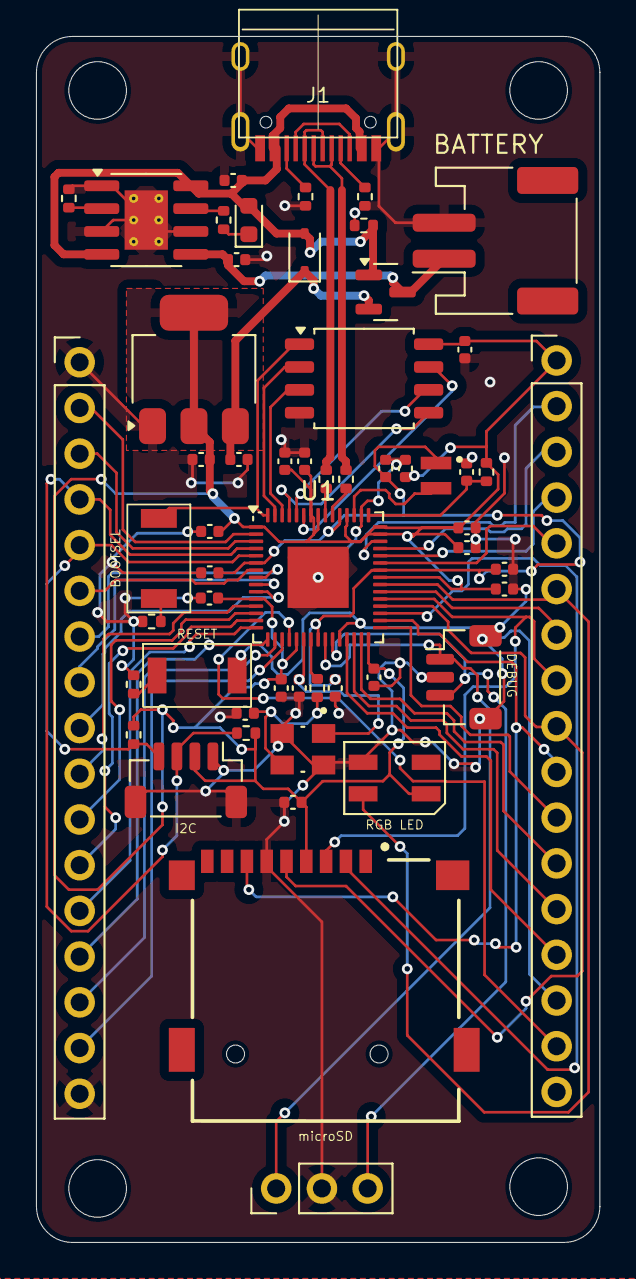
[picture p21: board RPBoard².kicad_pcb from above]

Board: 2 copper layers, 31.3 x 67.0 mm, 60 parts (0 on the bottom side), 61 nets.

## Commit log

2025-07-30 added july 29 journal entry and all project files
    [BOM.csv, RPBoard².kicad_pcb, RPBoard².kicad_sch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]
2025-08-25 updated PCB image in readme
2025-08-25 updated gerbers to add thermal vias
